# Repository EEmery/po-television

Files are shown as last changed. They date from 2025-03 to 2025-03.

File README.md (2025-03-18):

# Pocket Operator Television

The pocket operator television is a DIY device designed to display animations in sync with one or
more pocket operators. It uses PO-Sync to automatically synchronise the animation frames to your
music. It works in SY5 mode, if you want to chain together more devices, or in SY4 mode, if you want
to connect a headset, speaker, etc.

The PO television allows you to switch between animation patterns with the press of a button. It
comes preloaded with a few animations, but you can easily add your own "animation samples" to the
code.

The pocket operator television is made entirely from off-the-shelf components and 3D printed parts.
Its design tries to mimic the pocket operator: exposed black circuit boards, gold parts and strong
colors in prominent parts. It's easy to build one for yourself!

[Introducing the Pocket Operator Television - YouTube
Video](https://www.youtube.com/shorts/iwwsih4J6I4)

You can learn more details about the building process in the blog post:
- [Making the Pocket Operator Television - by Eduardo
  Emery](https://robotsandcoffeeco.substack.com/p/making-the-pocket-operator-television) (English)
- [Criando o Pocket Operator Television - by Eduardo
  Emery](https://robosecafe.substack.com/p/criando-o-pocket-operator-television) (Português)

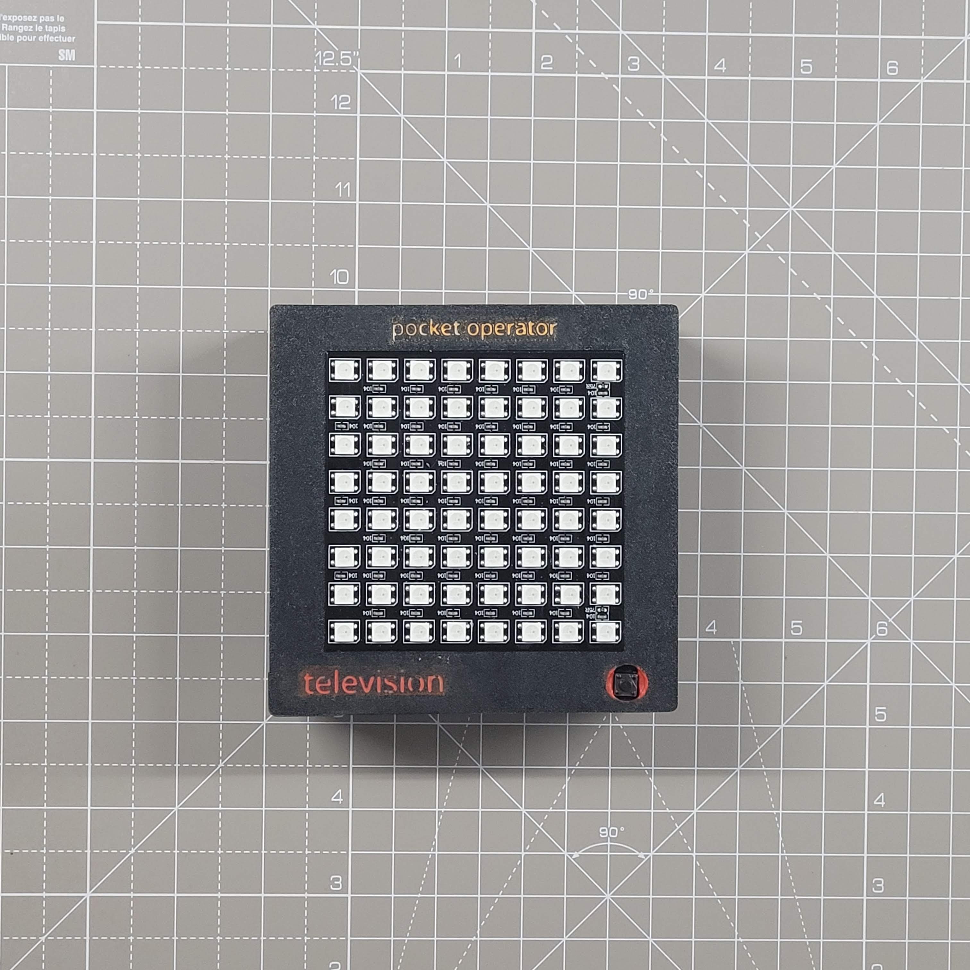
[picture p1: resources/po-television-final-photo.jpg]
Pocket Operator Television


## Index

1. [Electronics](#electronics)
    - [Component List](#component-list)
    - [The circuit](#the-circuit)
2. [Hardware](#hardware)
3. [The Code](#the-code)
    - [Setup](#setup)
    - [Diving into the code](#diving-into-the-code)
    - [Adding your own animation](#adding-your-own-animation)

## Electronics

### Component List
- 1x Raspberry Pi Pico W – the brains of the PO television
- 2x 3.5m audio jack – this will act as the input and output line of the device
- 1x button – to toggle between animations
- 2x switches – one to turn the device on/off and one to toggle between synchronization modes
  (SY4/SY5)
- 1x LED matrix display (8x8) – to output our animations
- 1x level shifter – to convert the 3.3V signal from the Raspberry Pi into a 5V signal to send to
  the display
- 1x step-down buck converter – to convert an external power supply to 5V and power our circuit
- 1x AAA battery holder – you can use other power supplies since we will be using a step-down buck
  converter, but I would recommend AAAs since they are the same ones used in the pocket operator, so
  you don't need to carry around several different types with you you
- 5x 100k 1 ohm resistors, 1x 470 ohm resistor and 1x 1000uF capacitor – these will be used
  throughout the circuit, more details below

### The circuit

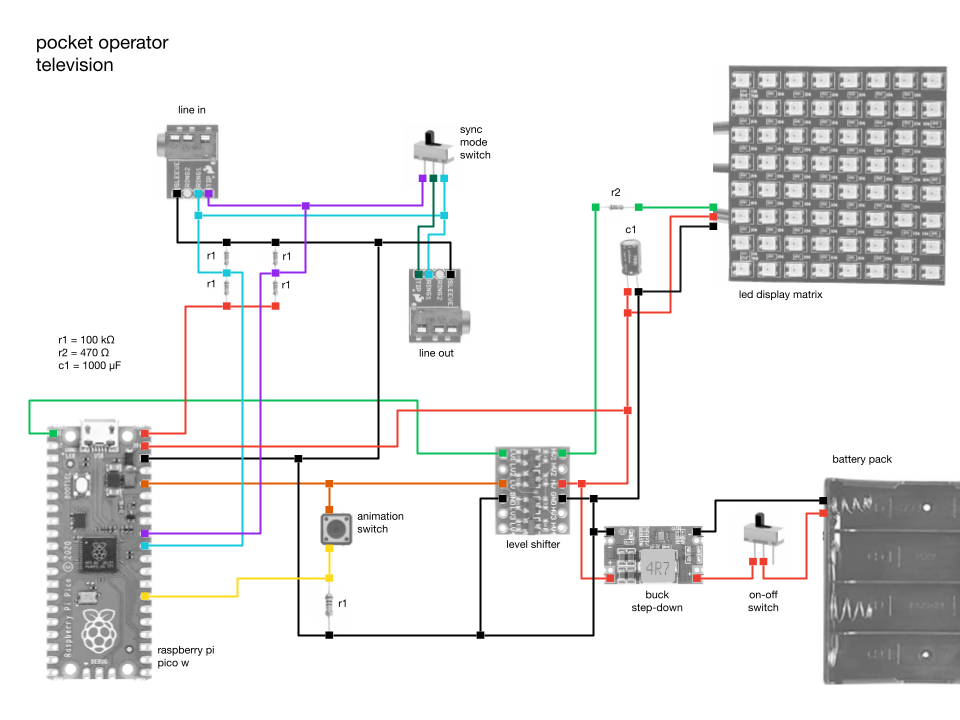
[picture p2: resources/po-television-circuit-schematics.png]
Pocket Operator Television - Circuit Diagram


**Notes on reading the audio input signal**

We want to listen to two signals coming from the line-in of the device: the PO-Sync signal and the
audio signal itself. We will pass both of these through a voltage divider (the `r1` resistors)
rather than reading directly from the source. Since the voltage division is done in half, we don't
need to use 100k ohms resistors specifically, you can use any value as long as they are the same.

**Notes on connecting the animation switch button**

The `r1` resistor connected to the power button ensures that we have a ground reference for when the
button is not pressed. I used a 100k ohms resistor since I was already using one of the same value
in the voltage divider circuit for reading the line-in signal, as explained above. Here, you can
also use different values for this resistor in the animation toggle button, if you prefer.

**Notes on the PO-Sync Mode Switch**

Between the audio input and output, there is a switch that allows you to switch between SY5 mode,
which passes the PO-Sync clock signal through to other devices that can be daisy-chained, and SY4
mode, which copies the audio signal to both inputs and allows you to listen to the sound through a
speaker or headphones in the line-out.

**Notes on connecting the LED matrix display**

I connected the LED matrix display as recommended by the [Adafruit team in the NeoPixel
guide](https://learn.adafruit.com/adafruit-neopixel-uberguide/basic-connections). You can learn more
about how to use them properly there, especially if you want to modify your pocket operator
television to work with different displays or LED strips.

## Hardware

The 3D printed case is very simple. It is meant to hold the display, circuit board, and animation
toggle button together. The LED matrix display I purchased came with a JST cable soldered to it, so
I used that to connect to the board. For consistency, I also used a JST cable to connect the
animation toggle button to the circuit board. The main case and back cover can be joined together
using M2 screws and nuts.

You can find the 3D models I used in the `.stl` files [in the `models`
folder](https://github.com/EEmery/po-television/tree/main/models). Feel free to modify them to
better suit your needs, as you may need to change them to fit your circuit board and display if they
don't have the same dimensions as mine.

## The code

### Setup

You can download the repository as a `.zip` or clone the repository with `git clone
git@github.com:EEmery/po-television.git`. The code uses MicroPython and you will need to install the
firmware on your board, [but it is a simple
process](https://projects.raspberrypi.org/en/projects/getting-started-with-the-pico/3).

Once you have the repository and the firmware installed, we can copy the files from the local `src/`
folder to the board you are using. This repository sets in the requirements file
(`requirements/dev.txt`) a series of tools to facilitate development with MicroPython, such as
`thonny`, `rshell` and `pipkin`. To activate the virtual environment with these tools, simply run
the following in your terminal:

1. `python3 -m venv .venv`
2. `source .venv/bin/activate`
3. `python3 -m pip install -r requirements/dev.txt`

The repository already contains the files for the `neopixel` library, which is used to communicate
with the LED display, so you don't need to install it. But, if you feel the need to reinstall this
library, just run the command below while your computer is connected to your board:

```
python3 -m pipkin install neopixel
```

To send the code from your local repository to the board, just use the `rshell` copy command:

```
rshell cp -r src/* pyboard/
```

If you prefer to develop with `Thonny`, which is quite popular when it comes to MicroPython
development, instead of using `pipkin` to install the libraries and `rshell` to send the code to the
board, just run:

```
python3 -m thonny
```

### Diving into the code

We basically have something similar to a "sense-plan-act" structure, common in the world of
robotics. The code first reads the audio input signal and processes it into parameters that are
easier to consume in the following steps.

At each step change (clock pulse), we call the animation function to request a new frame to be
displayed. This is the "planning" phase of our framework. We pass to the animation function some
parameters that we were able to collect from the pocket operator, so that we can use them (or not)
to construct the next frame. The list of parameters [can be seen in the
code](https://github.com/EEmery/po-television/blob/main/src/animation_robot_eyes.py#L141-L168).

The animation function will [return 2
parameters](https://github.com/EEmery/po-television/blob/main/src/animation_robot_eyes.py#L190). The
first is the new frame, which consists of a 2D 8x8 list where each value is a triplet (tuple)
representing the pixel's RGB values (red-green-blue). Each element in the pixel can range from 0
to 255. The second value it returns is called `memory` and should be used however the developer
wishes. The idea behind this is to allow any "state" to be passed between the previous function call
and the current one, so that the code can "remember" relevant information from its previous
executions. This could have been achieved with an object instead of a function, but I feel like it
could have made the code a bit more complex to modify, given that a "state" can be achieved with a
simple function parameter, like the one we used.

Finally, with a new frame in hand, we update the display with it. This is our "action" stage of the
framework and the end. We then proceed to the loop and start "sensing" the signal at the audio input
once again.

During this loop, we also keep checking to see if the animation button has been pressed. When this
happens, the code switches the animation function from a list of available animation functions for
use.

### Adding your own animation

Adding your animation is easy, you can start by replicating some of the existing animations to
create your own.

**1. Robotic arm animation
[`animation_robot_arm.py`](https://github.com/EEmery/po-television/blob/main/src/animation_robot_arm.py)**

This is the simplest of all the animation functions. Basically, we have 16 frames in the animation
and we iterate one by one as the function is called in a new step. This function does not use most
of the arguments passed to it. The code is commented for better understanding.

**2. Wave animation
[`animation_wave.py`](https://github.com/EEmery/po-television/blob/main/src/animation_wave.py)**

This animation is very similar to the previous one, with the difference that it allows you to use
any number of frames, it does not have to be exactly 16, which ends up making the code flexible to
be reused frequently.

Here, we save the cursor information of the current animation in memory to remember where we left
off in the next function call. This way, we can iterate through the frames one by one. The code is
commented for better understanding.

**3. Robotic eye animation
[`animation_robot_eyes.py`](https://github.com/EEmery/po-television/blob/main/src/animation_robot_eyes.py)**

As mentioned before, the animation `animation_wave.py` serves as a good template to be replicated in
other animations, since it allows the flexibility of any number of frames. This animation,
`animation_robot_eyes`, is practically a copy of `animation_wave`, with the only difference being
the frames used, which form a different drawing.

**4. Music visualization animation
[`animation_music_visualization.py`](https://github.com/EEmery/po-television/blob/main/src/animation_music_visualization.py)**

This is a slightly more complex animation, compared to the others. It serves mainly to demonstrate a
possible use of the parameters that are calculated from the audio input of the pocket operator. In
it, we draw a representation of the intensity of the sound signal in each of the steps. The code is
commented in each step for better understanding.

**Add a call to your new animation function**

Whether you are copying an existing animation and modifying it or creating a new one from scratch,
you need to add a call to the new function in the main loop of the code. To do this, in the
`main.py` file, simply [import the
function](https://github.com/EEmery/po-television/blob/main/src/main.py#L3-L6) and add it to [the
list of functions called
`ANIMATIONS`](https://github.com/EEmery/po-television/blob/main/src/main.py#L8-L14).

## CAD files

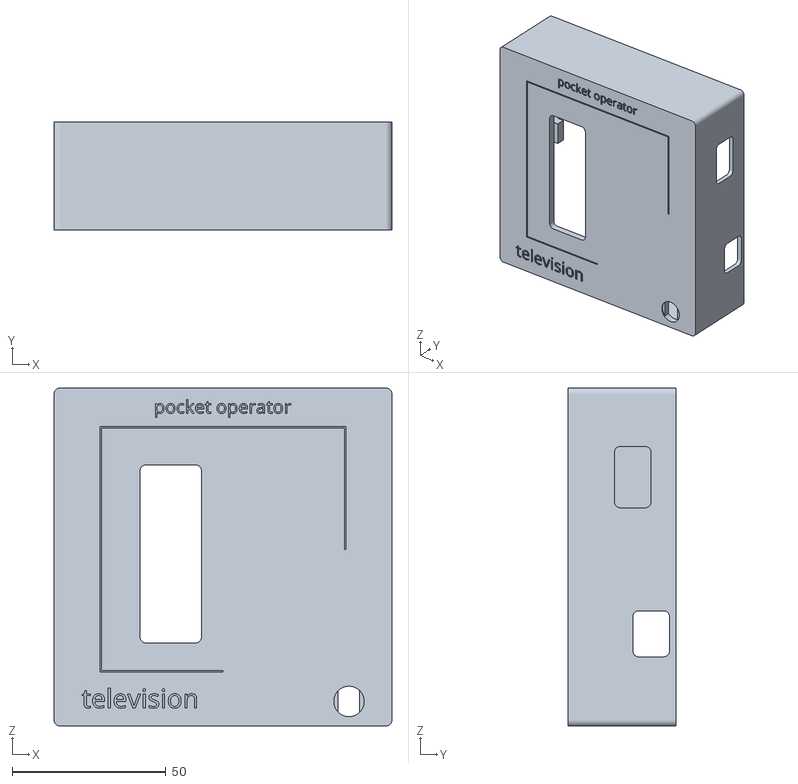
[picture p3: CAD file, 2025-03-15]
models/PO-TV Main.stl
110.0 x 35.0 x 110.0

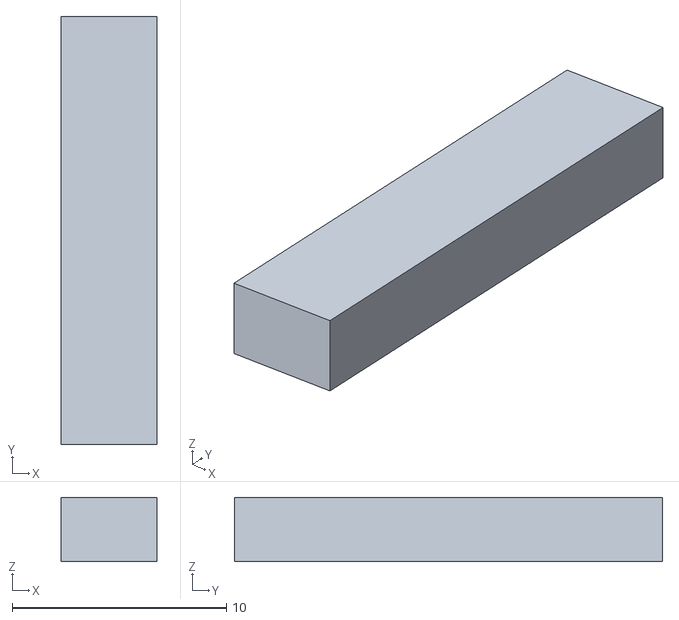
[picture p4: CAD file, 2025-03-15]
models/PO-TV Button Holder.stl
4.50 x 20.0 x 3.00

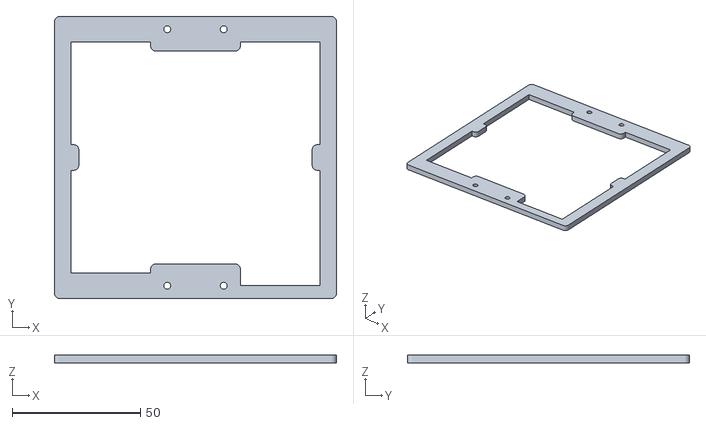
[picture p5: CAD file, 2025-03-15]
models/PO-TV Back.stl
110.0 x 110.0 x 3.00

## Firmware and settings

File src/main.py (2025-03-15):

from pocket_operator import PocketOperator
from television import Television
from animation_robot_arm import robot_arm
from animation_robot_eyes import robot_eyes
from animation_wave import wave
from animation_music_visualization import music_visualization

# A list with all the available animations that the pocket operator television should iterate over
ANIMATIONS = [
    robot_arm,
    robot_eyes,
    wave,
    music_visualization,
]

SOUND_SIGNAL_PIN = 26    # Pin that reads the line-in music channel
CLOCK_SIGNAL_PIN = 27    # Pin that reads the line-in PO-Sync channel
MAX_STEPS = 16           # Maximum number of steps that the pocket operator has
SIGNAL_THRESHOLD = 2000  # Threshold used to detect a new clock pulse from the PO-Sync signal

DISPLAY_WIDTH = 8        # Width of the LED matrix display used
DISPLAY_HEIGHT = 8       # Height of the LED matrix display used
DISPLAY_KHZ = 400        # Some displays can communicate at 800 KHZ, others at 400 KHZ
DISPLAY_PIN = 0          # Pin that connects to the display data-in cable
DISPLAY_BUTTON_PIN = 21  # Pin that reads the signal from the animation button switch

# Initialize a representation of the pocket operator with the right parameters
po = PocketOperator(
    SOUND_SIGNAL_PIN,
    CLOCK_SIGNAL_PIN,
    MAX_STEPS,
    SIGNAL_THRESHOLD,
)

# Initialize a representation of the pocket operator television with the right parameters
tv = Television(
    DISPLAY_PIN,
    DISPLAY_BUTTON_PIN,
    DISPLAY_WIDTH,
    DISPLAY_HEIGHT,
    DISPLAY_KHZ,
    ANIMATIONS,
)

while True:
    # Reads data from the pocket operator
    (
        po.read_gpios()
        .update_step()
        .update_cumulative_values()
    )

    if po.has_changed_step:
        # Updates the display once we detect a change in step
        (
            tv.read_animation_change_button()
            .draw_new_frame(
                po.step_num,
                po.sound_signal,
                po.prev_step_sound_avg,
                po.prev_step_sound_max
            )
        )

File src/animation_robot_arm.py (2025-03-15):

# RGB (read-green-blue) values for each high (H) and low (L) pixel in the animation. The color
# value can go from 0 to 255. Have in mind that those LEDs are very bright, so a low intensity
# should be enough to get a good effect from the display.
L = (0, 0, 0)
H = (10, 10, 10)

robot_arm_frames = [
    # 1 - 4
    [
        [L, L, L, L, L, L, L, L],
        [L, L, L, L, L, L, L, L],
        [H, H, L, L, L, L, L, L],
        [H, H, H, H, L, L, L, L],
        [L, L, L, L, H, L, L, L],
        [L, L, L, L, L, H, L, L],
        [L, L, L, L, H, L, L, L],
        [L, L, L, H, L, L, L, L],
    ],
    [
        [L, L, L, L, L, L, L, L],
        [L, L, L, L, L, L, L, L],
        [H, H, L, L, L, L, L, L],
        [H, H, H, H, L, L, L, L],
        [L, L, L, L, H, L, L, L],
        [L, L, L, L, L, H, L, L],
        [L, L, L, L, H, L, L, L],
        [L, L, L, H, L, L, L, L],
    ],
    [
        [L, L, L, L, L, L, L, L],
        [L, H, H, L, L, L, L, L],
        [L, H, H, L, L, L, L, L],
        [L, L, L, H, L, L, L, L],
        [L, L, L, L, H, L, L, L],
        [L, L, L, L, L, H, L, L],
        [L, L, L, L, H, L, L, L],
        [L, L, L, H, L, L, L, L],
    ],
    [
        [L, L, L, L, L, L, L, L],
        [L, L, H, H, L, L, L, L],
        [L, L, H, H, L, L, L, L],
        [L, L, L, H, L, L, L, L],
        [L, L, L, L, H, L, L, L],
        [L, L, L, L, H, L, L, L],
        [L, L, L, L, H, L, L, L],
        [L, L, L, H, L, L, L, L],
    ],

    # 5 - 8
    [
        [L, L, L, L, L, L, L, L],
        [L, L, H, H, L, L, L, L],
        [L, L, H, H, L, L, L, L],
        [L, L, L, H, L, L, L, L],
        [L, L, L, H, L, L, L, L],
        [L, L, L, H, L, L, L, L],
        [L, L, L, H, L, L, L, L],
        [L, L, L, H, L, L, L, L],
    ],
    [
        [L, L, L, L, L, L, L, L],
        [L, L, L, H, H, L, L, L],
        [L, L, L, H, H, L, L, L],
        [L, L, L, H, L, L, L, L],
        [L, L, L, H, L, L, L, L],
        [L, L, L, H, L, L, L, L],
        [L, L, L, H, L, L, L, L],
        [L, L, L, H, L, L, L, L],
    ],
    [
        [L, L, L, L, L, L, L, L],
        [L, L, L, L, H, H, L, L],
        [L, L, L, L, H, H, L, L],
        [L, L, L, L, H, L, L, L],
        [L, L, L, H, L, L, L, L],
        [L, L, L, H, L, L, L, L],
        [L, L, L, H, L, L, L, L],
        [L, L, L, L, H, L, L, L],
    ],
    [
        [L, L, L, L, L, L, L, L],
        [L, L, L, L, L, H, H, L],
        [L, L, L, L, L, H, H, L],
        [L, L, L, L, H, L, L, L],
        [L, L, L, H, L, L, L, L],
        [L, L, H, L, L, L, L, L],
        [L, L, L, H, L, L, L, L],
        [L, L, L, L, H, L, L, L],
    ],

    # 9 - 12
    [
        [L, L, L, L, L, L, L, L],
        [L, L, L, L, L, L, L, L],
        [L, L, L, L, L, L, H, H],
        [L, L, L, L, H, H, H, H],
        [L, L, L, H, L, L, L, L],
        [L, L, H, L, L, L, L, L],
        [L, L, L, H, L, L, L, L],
        [L, L, L, L, H, L, L, L],
    ],
    [
        [L, L, L, L, L, L, L, L],
        [L, L, L, L, L, L, L, L],
        [L, L, L, L, L, L, H, H],
        [L, L, L, L, H, H, H, H],
        [L, L, L, H, L, L, L, L],
        [L, L, H, L, L, L, L, L],
        [L, L, L, H, L, L, L, L],
        [L, L, L, L, H, L, L, L],
    ],
    [
        [L, L, L, L, L, L, L, L],
        [L, L, L, L, L, H, H, L],
        [L, L, L, L, L, H, H, L],
        [L, L, L, L, H, L, L, L],
        [L, L, L, H, L, L, L, L],
        [L, L, H, L, L, L, L, L],
        [L, L, L, H, L, L, L, L],
        [L, L, L, L, H, L, L, L],
    ],
    [
        [L, L, L, L, L, L, L, L],
        [L, L, L, L, H, H, L, L],
        [L, L, L, L, H, H, L, L],
        [L, L, L, L, H, L, L, L],
        [L, L, L, H, L, L, L, L],
        [L, L, L, H, L, L, L, L],
        [L, L, L, H, L, L, L, L],
        [L, L, L, L, H, L, L, L],
    ],

    # 13 - 16
    [
        [L, L, L, L, L, L, L, L],
        [L, L, L, H, H, L, L, L],
        [L, L, L, H, H, L, L, L],
        [L, L, L, H, L, L, L, L],
        [L, L, L, H, L, L, L, L],
        [L, L, L, H, L, L, L, L],
        [L, L, L, H, L, L, L, L],
        [L, L, L, H, L, L, L, L],
    ],
    [
        [L, L, L, L, L, L, L, L],
        [L, L, H, H, L, L, L, L],
        [L, L, H, H, L, L, L, L],
        [L, L, L, H, L, L, L, L],
        [L, L, L, H, L, L, L, L],
        [L, L, L, H, L, L, L, L],
        [L, L, L, H, L, L, L, L],
        [L, L, L, H, L, L, L, L],
    ],
    [
        [L, L, L, L, L, L, L, L],
        [L, L, H, H, L, L, L, L],
        [L, L, H, H, L, L, L, L],
        [L, L, L, H, L, L, L, L],
        [L, L, L, L, H, L, L, L],
        [L, L, L, L, H, L, L, L],
        [L, L, L, L, H, L, L, L],
        [L, L, L, H, L, L, L, L],
    ],
    [
        [L, L, L, L, L, L, L, L],
        [L, H, H, L, L, L, L, L],
        [L, H, H, L, L, L, L, L],
        [L, L, L, H, L, L, L, L],
        [L, L, L, L, H, L, L, L],
        [L, L, L, L, L, H, L, L],
        [L, L, L, L, H, L, L, L],
        [L, L, L, H, L, L, L, L],
    ],
]


def robot_arm(step_num, sound_level, prev_step_sound_avg, prev_step_sound_max, memory):
    """Iterates over all the frames in each new step, forming a robotic arm amimation. The animation
    expects exactly 16 frames, to match with the number of steps in the pocket operator.

    Args:
        step_num (int): Equivalent step count in the pocket operator, goes from 0 to 15 (or
                        `MAX_STEPS`)
        sound_level (int): Most recent read from the GPIO pin connected to the line-in sound channel
                           in the pocket operator. This value won't be used in this animation
                           function
        prev_step_sound_avg (float): The previous step average value of the GPIO pin connected to
                                     the line-in sound channel in the pocket operator. This value
                                     won't be used in this animation function
        prev_step_sound_max (int): The previous step maximum value of the GPIO pin connected to the
                                   line-in sound channel in the pocket operator. This value won't be
                                   used in this animation function

    Returns:
        frame (Frame): A 2D list of Tuples containing the pixel RGB values forming the new frame to
                       be drawn, in other words, a `List[List[Tuple[int, int, int]]]`) in the shape
                       of (row, column, red-value, green-value, blue-value)
        memory (Any): Any data structure that should be passed to the next call of the animation
                      function. On the first animation function call, it comes as None. This is an
                      optional feature to be used if necessary, it can be left as None if not used
    """
    # We simply iterate over the frames according to the current step number, since we expect
    # exaclty 16 frames in the animation
    frame = robot_arm_frames[step_num-1]

    # Returns the new frame and the unused memory (it's value will remaing being None)
    return frame, memory
